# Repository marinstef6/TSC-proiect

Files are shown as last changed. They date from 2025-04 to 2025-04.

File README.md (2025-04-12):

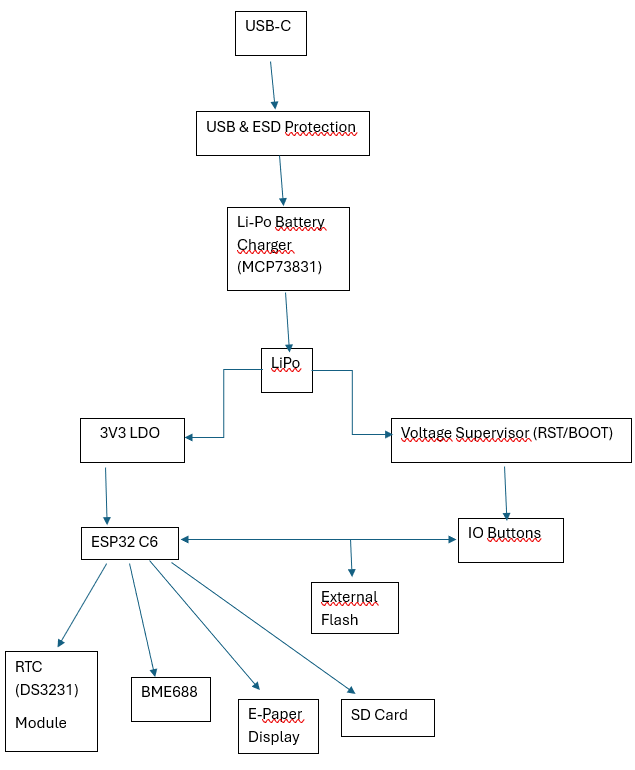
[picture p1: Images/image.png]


**Descriere functionalitate hardware**

Proiectul are la baza microcontroller-ul ESP32-C6, care gestioneaza comunicarea cu toate componentele externe si senzorii conectati. Acest microcontroller ofera conectivitate Wifi si Bluetooth dar si suport pentru interfetele SPI, I2C si UART. Este conectat la 3.3V printr-un regulator de tensiune LDO, acesta primind energie de la o baterie Li-po de 3.7V.
Afisarea informatiile se face utilizand un display E-Paper care este conectat prin inteerfata SPI, oferind un consum redus de energie, acstea fiind mai activ doar cand se fac actualizari pentru ecran. Informatiile pe care le va afisa sunt data, ora, valori senzori etc.
Monitorizarea mediului se face cu ajutorul senzorului BME688, acesta masurand temperatura, umiditatea dar si presiunea atmosferica. Comunica cu microcontroller-ul prin magistrala I2C.
Modulul RTC DS3231 este conectat tot la I2C si mentine ora si data exacta, chiar daca sistemul va fi oprit.
Prin portul USB-C se va face alimentarea sistemuluo care este conectat la circuitul de incarcare de baterie, acesta folosind MCP73831 si astfel controland incarcarea bateriei Li-Po. Tensiunea va fi stabilita la 3.3V pentru alimentarea senzorilor si a microcontroller-ului. 
Circuitul MAX17048 este folosit pentru a monitoriza nivelul incarcarii bateriei si ofera informatii despre tensiune si starea de incarcare prin I2C.
Consumul de energie este dat de ESP32-C6 care va putea sa intre in modul de consum redus si permite functionarea pe termen lung a bateriei. Consumul in regim activ este facut in functie de sarcinile si componentele active in acel moment.
Pentru a stoca, sistemul va folosi o memorie externa de tip NOR Flash conectata cu ajutorul lui SPI dar vom avea si un slot de card SD. Acesta va fi folosit pentru a loga local datele. Butoanele sunt conectate la GPIO-uri si vor fi folosite pentru reset, boot si alte actiuni. 

**Bill Of Materials**

| Componentă | Datasheet | Link produs |
|---|---|---|
| ESP32-C6-WROOM-1-N8 | [Datasheet](https://ro.mouser.com/datasheet/2/891/Espressif_ESP32_C6_WROOM_1__Datasheet_V0_1_PRELIMI-3239987.pdf) | [Link](https://ro.mouser.com/ProductDetail/Espressif-Systems/ESP32-C6-WROOM-1-N8?qs=8Wlm6%252BaMh8ST02Gmwp74cw%3D%3D) |
| MCP73831 | [Datasheet](https://ww1.microchip.com/downloads/aemDocuments/documents/APID/ProductDocuments/DataSheets/MCP73831-Family-Data-Sheet-DS20001984H.pdf) | [Link](https://store.comet.srl.ro/Catalogue/Product/15728/) |
| MAX17048G+T10 | [Datasheet](https://ro.mouser.com/datasheet/2/609/MAX17048_MAX17049-3469099.pdf) | [Link](https://ro.mouser.com/ProductDetail/Analog-Devices-Maxim-Integrated/MAX17048G%2bT10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) |
| USBLC6-2SC6Y | [Datasheet](https://ro.mouser.com/datasheet/2/389/usblc6_2sc6y-1852505.pdf) | [Link](https://ro.mouser.com/ProductDetail/STMicroelectronics/USBLC6-2SC6Y?qs=gNDSiZmRJS%2FOgDexvXkdow%3D%3D) |
| PFMF.050.2 | [Datasheet](https://ro.mouser.com/datasheet/2/358/typ_PFMF-1275918.pdf) | [Link](https://ro.mouser.com/ProductDetail/Schurter/PFMF.050.2?qs=1auRipcfynCums5v1iucSA%3D%3D)|
| SD0805S020S1R0 | [Datasheet](https://ro.mouser.com/datasheet/2/40/schottky-3165252.pdf) | [Link](https://ro.mouser.com/ProductDetail/KYOCERA-AVX/SD0805S020S1R0?qs=jCA%252BPfw4LHbpkAoSnwrdjw%3D%3D) |
| DMG2305UX-7 | [Datasheet](https://www.diodes.com/assets/Datasheets/DMG2305UX.pdf) | [Link](https://ro.mouser.com/ProductDetail/Diodes-Incorporated/DMG2305UX-7?qs=L1DZKBg7t5F%2FNBHrjfxC%252Bg%3D%3D)|
| XC6220A331MR-G (IC4)  | [Datasheet](https://ro.mouser.com/datasheet/2/760/xc6220-3371556.pdf) | [Link](https://ro.mouser.com/ProductDetail/Torex-Semiconductor/XC6220A331MR-G?qs=AsjdqWjXhJ8ZSWznL1J0gg%3D%3D) |
| 112A-TAAR-R03 (J4) | [Datasheet](https://store.comet.bg/download-file.php?id=27596) | [Link](https://store.comet.srl.ro/Catalogue/Product/43497/)|
| MBR0530T3G | [Datasheet](https://www.onsemi.com/products/discrete-power-modules/schottky-diodes-schottky-rectifiers/mbr0530t3g) | [Link](https://ro.mouser.com/ProductDetail/onsemi/MBR0530T3G?qs=3JMERSakebpEmdUS6GetdQ%3D%3D) |  
| MCP73831-2ACI/MC (U5) | [Datasheet](https://ro.mouser.com/datasheet/2/268/MCP73831_Family_Data_Sheet_DS2001984H-3441711.pdf) | [Link](https://ro.mouser.com/ProductDetail/Microchip-Technology/MCP73831-2ACI-MC?qs=hH%252BOa0VZEiBneYTVdpuVdg%3D%3D) |
| FH34SRJ-24S-0.5SH(99) (J1) | [Datasheet](https://ro.mouser.com/datasheet/2/185/FH34SRJ_24S_0_5SH_99__CL0580_1255_6_99_2DDrawing_0-1615044.pdf) | [Link](https://ro.mouser.com/ProductDetail/Hirose-Connector/FH34SRJ-24S-0.5SH99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) |
| DMG2305UX-7 | [Datasheet](https://www.diodes.com/assets/Datasheets/DMG2305UX.pdf) | [Link](https://ro.mouser.com/ProductDetail/Diodes-Incorporated/DMG2305UX-7?qs=L1DZKBg7t5F%2FNBHrjfxC%252Bg%3D%3D) |
| BME688 | [Datasheet](https://ro.mouser.com/datasheet/2/783/bst_bme688_fl000-2307034.pdf) | [Link](https://ro.mouser.com/ProductDetail/Bosch-Sensortec/BME688?qs=IS%252B4QmGtzzqQoVDscqwx3A%3D%3D) |
| BD5229G-TR (IC1) | [Datasheet](https://fscdn.rohm.com/en/products/databook/datasheet/ic/power/voltage_detector/bd52xxg-e.pdf) | [Link](https://ro.mouser.com/ProductDetail/ROHM-Semiconductor/BD5229G-TR?qs=4kLU8WoGk0vvnhrrYwdszw%3D%3D) |
| DS3231SN# (U3) | [Datasheet](https://ro.mouser.com/datasheet/2/609/DS3231-3421123.pdf) | [Link](https://ro.mouser.com/ProductDetail/Analog-Devices-Maxim-Integrated/DS3231SN?qs=1eQvB6Dk1vhUlr8%2FOrV0Fw%3D%3D) |
| CPH3225A | [Datasheet](https://ro.mouser.com/datasheet/2/360/Seiko_Instruments_MicroBattery_E_20230330_2024Jan_-3561061.pdf) | [Link](https://ro.mouser.com/ProductDetail/Seiko-Semiconductors/CPH3225A?qs=3etwrb1wR%252BhUOph6lAO7eg%3D%3D) |
| PGB1010603MR | [Datasheet](https://www.littelfuse.com/assetdocs/pulseguard-esd-suppressors-pgb1-datasheet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) | [Link](https://ro.mouser.com/ProductDetail/Littelfuse/PGB1010603MR?qs=gu7KAQ731URLg4GSnNNN7Q%3D%3D) |
| W25Q512JVEIQ (U1) | [Datasheet](https://ro.mouser.com/datasheet/2/949/Winbond_W25Q512JV_Datasheet-3240039.pdf) | [Link](https://ro.mouser.com/ProductDetail/Winbond/W25Q512JVEIQ?qs=l7cgNqFNU1jw6svr3at6tA%3D%3D) |
| Qwiic connector 4-pin Accessories (J3) | [Datasheet]() | [Link](https://ro.mouser.com/ProductDetail/Adafruit/4208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) |
| C1 | [Datasheet](https://ro.mouser.com/datasheet/2/447/UPY_GPHC_X7R_6_3V_to_250V_24-3441574.pdf) | [Link](https://ro.mouser.com/ProductDetail/YAGEO/CC0402KRX7R7BB104?qs=AgBp2OyFlx%252BSOyhfyS7hpw%3D%3D) |
| C2 | [Datasheet](https://ro.mouser.com/datasheet/2/447/UPY_GPHC_X7R_6_3V_to_250V_24-3441574.pdf) | [Link](https://ro.mouser.com/ProductDetail/YAGEO/CC0402KRX7R7BB104?qs=AgBp2OyFlx%252BSOyhfyS7hpw%3D%3D) |
| C1_BAT | [Datasheet](https://ro.mouser.com/datasheet/2/447/upy_gphc_x5r_4v_to_50v-3461255.pdf) | [Link](https://ro.mouser.com/ProductDetail/YAGEO/CC0402MPX5R5BB475?qs=mzRxyRlhVdsRoWExm6hPvg%3D%3D) |
| C1_BAT1 | [Datasheet](https://ro.mouser.com/datasheet/2/447/upy_gphc_x5r_4v_to_50v-3461255.pdf) | [Link](https://ro.mouser.com/ProductDetail/YAGEO/CC0402MPX5R5BB475?qs=mzRxyRlhVdsRoWExm6hPvg%3D%3D) | 
| C1_BAT2 | [Datasheet](https://ro.mouser.com/datasheet/2/447/upy_gphc_x5r_4v_to_50v-3461255.pdf) | [Link](https://ro.mouser.com/ProductDetail/YAGEO/CC0402MPX5R5BB475?qs=mzRxyRlhVdsRoWExm6hPvg%3D%3D) |  
| C2_BAT | [Datasheet](https://ro.mouser.com/datasheet/2/447/upy_gphc_x5r_4v_to_50v-3461255.pdf) | [Link](https://ro.mouser.com/ProductDetail/YAGEO/CC0402MPX5R5BB475?qs=mzRxyRlhVdsRoWExm6hPvg%3D%3D) |
| C4 | [Datasheet](https://ro.mouser.com/datasheet/2/447/upy_gphc_x5r_4v_to_50v-3461255.pdf) | [Link](https://ro.mouser.com/ProductDetail/YAGEO/CC0402KPX5R8BB105?qs=mzRxyRlhVduNCG5kLC2PGw%3D%3D) |
| C3 | [Datasheet]() | [Link]() |
| C4_USB | [Datasheet](https://ro.mouser.com/datasheet/2/447/UPY_GPHC_X7R_6_3V_to_250V_24-3441574.pdf) | [Link](https://ro.mouser.com/ProductDetail/YAGEO/CC0402KRX7R7BB104?qs=AgBp2OyFlx%252BSOyhfyS7hpw%3D%3D) |
| C5 | [Datasheet](https://ro.mouser.com/datasheet/2/447/UPY_GPHC_X6S_4V_to_50V_5-3461239.pdf) | [Link](https://ro.mouser.com/ProductDetail/YAGEO/CC0402KRX6S8BB105?qs=W0yvOO0ixfHpmgj3WKoR4Q%3D%3D) |
| C5_USB | [Datasheet](https://ro.mouser.com/datasheet/2/447/upy_gphc_x5r_4v_to_50v-3461255.pdf) | [Link](https://ro.mouser.com/ProductDetail/YAGEO/CC0402MPX5R5BB475?qs=mzRxyRlhVdsRoWExm6hPvg%3D%3D) |
| C6 | [Datasheet](https://ro.mouser.com/datasheet/2/447/UPY_GPHC_X7R_6_3V_to_250V_24-3441574.pdf) | [Link](https://ro.mouser.com/ProductDetail/YAGEO/CC0402KRX7R7BB104?qs=AgBp2OyFlx%252BSOyhfyS7hpw%3D%3D) |
| C7 | [Datasheet](https://ro.mouser.com/datasheet/2/447/upy_gphc_x5r_4v_to_50v-3461255.pdf) | [Link](https://ro.mouser.com/ProductDetail/YAGEO/CC0402MRX5R4BB106?qs=tS%2FAHvPQ%2F561gTjBOiVihQ%3D%3D) |
| C8 | [Datasheet](https://ro.mouser.com/datasheet/2/447/UPY_GPHC_X7R_6_3V_to_250V_24-3441574.pdf) | [Link](https://ro.mouser.com/ProductDetail/YAGEO/CC0402KRX7R7BB104?qs=AgBp2OyFlx%252BSOyhfyS7hpw%3D%3D) |
| C9 | [Datasheet](https://ro.mouser.com/datasheet/2/447/UPY_GPHC_X7R_6_3V_to_250V_24-3441574.pdf) | [Link](https://ro.mouser.com/ProductDetail/YAGEO/CC0402KRX7R7BB104?qs=AgBp2OyFlx%252BSOyhfyS7hpw%3D%3D) |
| C10 | [Datasheet](https://ro.mouser.com/datasheet/2/447/UPY_GPHC_X7R_6_3V_to_250V_24-3441574.pdf) | [Link](https://ro.mouser.com/ProductDetail/YAGEO/CC0402KRX7R7BB104?qs=AgBp2OyFlx%252BSOyhfyS7hpw%3D%3D) |
| C10_SUPERCAP | [Datasheet](https://ro.mouser.com/datasheet/2/360/Seiko_Instruments_MicroBattery_E_20230330_2024Jan_-3561061.pdf) | [Link](https://ro.mouser.com/ProductDetail/Seiko-Semiconductors/CPH3225A?qs=3etwrb1wR%252BhUOph6lAO7eg%3D%3D) |
| CHANGE_BUTTON | [Datasheet](https://ro.mouser.com/datasheet/2/1490/SOF_data_sheet-3304259.pdf) | [Link](https://ro.mouser.com/ProductDetail/Mitsumi/SOF-232HNT?qs=Imq1NPwxi77Mt0U54xXTVA%3D%3D) |
| RESET_BUTTON | [Datasheet](https://ro.mouser.com/datasheet/2/1490/SOF_data_sheet-3304259.pdf) | [Link](https://ro.mouser.com/ProductDetail/Mitsumi/SOF-232HNT?qs=Imq1NPwxi77Mt0U54xXTVA%3D%3D) |
| BOOT_BUTTON | [Datasheet](https://ro.mouser.com/datasheet/2/1490/SOF_data_sheet-3304259.pdf) | [Link](https://ro.mouser.com/ProductDetail/Mitsumi/SOF-232HNT?qs=Imq1NPwxi77Mt0U54xXTVA%3D%3D) |  
| CHG_LED | [Datasheet]() | [Link]() |
| C_DELAY | [Datasheet](https://ro.mouser.com/datasheet/2/447/UPY_GPHC_X7R_6_3V_to_250V_24-3441574.pdf) | [Link](https://ro.mouser.com/ProductDetail/YAGEO/CC0402KRX7R7BB104?qs=AgBp2OyFlx%252BSOyhfyS7hpw%3D%3D) |
| D2 | [Datasheet](https://ro.mouser.com/datasheet/2/40/schottky-3165252.pdf) | [Link](https://ro.mouser.com/ProductDetail/KYOCERA-AVX/SD0805S020S1R0?qs=jCA%252BPfw4LHbpkAoSnwrdjw%3D%3D) |
| D3 | [Datasheet](https://www.onsemi.com/products/discrete-power-modules/schottky-diodes-schottky-rectifiers/mbr0530t3g) | [Link](https://ro.mouser.com/ProductDetail/onsemi/MBR0530T3G?qs=3JMERSakebpEmdUS6GetdQ%3D%3D) |
| D4 | [Datasheet](https://www.onsemi.com/products/discrete-power-modules/schottky-diodes-schottky-rectifiers/mbr0530t3g) | [Link](https://ro.mouser.com/ProductDetail/onsemi/MBR0530T3G?qs=3JMERSakebpEmdUS6GetdQ%3D%3D) |
| D5 | [Datasheet](https://www.onsemi.com/products/discrete-power-modules/schottky-diodes-schottky-rectifiers/mbr0530t3g) | [Link](https://ro.mouser.com/ProductDetail/onsemi/MBR0530T3G?qs=3JMERSakebpEmdUS6GetdQ%3D%3D) |
| D6 | [Datasheet](https://www.littelfuse.com/assetdocs/pulseguard-esd-suppressors-pgb1-datasheet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) | [Link](https://ro.mouser.com/ProductDetail/Littelfuse/PGB1010603MR?qs=gu7KAQ731URLg4GSnNNN7Q%3D%3D) |
| D7 | [Datasheet](https://ro.mouser.com/datasheet/2/40/schottky-3165252.pdf) | [Link](https://ro.mouser.com/ProductDetail/KYOCERA-AVX/SD0805S020S1R0?qs=jCA%252BPfw4LHbpkAoSnwrdjw%3D%3D) |
| D8 | [Datasheet](https://www.littelfuse.com/assetdocs/pulseguard-esd-suppressors-pgb1-datasheet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) | [Link](https://ro.mouser.com/ProductDetail/Littelfuse/PGB1010603MR?qs=gu7KAQ731URLg4GSnNNN7Q%3D%3D) |
| D9 | [Datasheet](https://www.littelfuse.com/assetdocs/pulseguard-esd-suppressors-pgb1-datasheet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) | [Link](https://ro.mouser.com/ProductDetail/Littelfuse/PGB1010603MR?qs=gu7KAQ731URLg4GSnNNN7Q%3D%3D) |
| D10 | [Datasheet](https://www.littelfuse.com/assetdocs/pulseguard-esd-suppressors-pgb1-datasheet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) | [Link](https://ro.mouser.com/ProductDetail/Littelfuse/PGB1010603MR?qs=gu7KAQ731URLg4GSnNNN7Q%3D%3D) |
| D11 | [Datasheet](https://www.littelfuse.com/assetdocs/pulseguard-esd-suppressors-pgb1-datasheet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) | [Link](https://ro.mouser.com/ProductDetail/Littelfuse/PGB1010603MR?qs=gu7KAQ731URLg4GSnNNN7Q%3D%3D) |
| D12 | [Datasheet](https://www.littelfuse.com/assetdocs/pulseguard-esd-suppressors-pgb1-datasheet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) | [Link](https://ro.mouser.com/ProductDetail/Littelfuse/PGB1010603MR?qs=gu7KAQ731URLg4GSnNNN7Q%3D%3D) |
| EPD_C1 | [Datasheet](https://ro.mouser.com/datasheet/2/396/TAIY_S_A0012396493_1-2514439.pdf) | [Link](https://ro.mouser.com/ProductDetail/TAIYO-YUDEN/UMK105CBJ105MV-F?qs=lkMpTOwszhfe5N0wQnb5vQ%3D%3D) |
| EPD_C2 | [Datasheet](https://ro.mouser.com/datasheet/2/396/TAIY_S_A0012396493_1-2514439.pdf) | [Link](https://ro.mouser.com/ProductDetail/TAIYO-YUDEN/UMK105CBJ105MV-F?qs=lkMpTOwszhfe5N0wQnb5vQ%3D%3D) |  
| EPD_C5 | [Datasheet](https://ro.mouser.com/datasheet/2/396/TAIY_S_A0012396493_1-2514439.pdf) | [Link](https://ro.mouser.com/ProductDetail/TAIYO-YUDEN/UMK105CBJ105MV-F?qs=lkMpTOwszhfe5N0wQnb5vQ%3D%3D) |
| EPD_C6 | [Datasheet](https://ro.mouser.com/datasheet/2/396/TAIY_S_A0012396493_1-2514439.pdf) | [Link](https://ro.mouser.com/ProductDetail/TAIYO-YUDEN/UMK105CBJ105MV-F?qs=lkMpTOwszhfe5N0wQnb5vQ%3D%3D) |
| EPD_C7 | [Datasheet](https://ro.mouser.com/datasheet/2/396/TAIY_S_A0012396493_1-2514439.pdf) | [Link](https://ro.mouser.com/ProductDetail/TAIYO-YUDEN/UMK105CBJ105MV-F?qs=lkMpTOwszhfe5N0wQnb5vQ%3D%3D) |
| EPD_C8 | [Datasheet](https://ro.mouser.com/datasheet/2/396/TAIY_S_A0012396493_1-2514439.pdf) | [Link](https://ro.mouser.com/ProductDetail/TAIYO-YUDEN/UMK105CBJ105MV-F?qs=lkMpTOwszhfe5N0wQnb5vQ%3D%3D) |
| EPD_C9 | [Datasheet](https://ro.mouser.com/datasheet/2/396/TAIY_S_A0012396493_1-2514439.pdf) | [Link](https://ro.mouser.com/ProductDetail/TAIYO-YUDEN/UMK105CBJ105MV-F?qs=lkMpTOwszhfe5N0wQnb5vQ%3D%3D) |
| EPD_C10 | [Datasheet](https://ro.mouser.com/datasheet/2/396/TAIY_S_A0012396493_1-2514439.pdf) | [Link](https://ro.mouser.com/ProductDetail/TAIYO-YUDEN/UMK105CBJ105MV-F?qs=lkMpTOwszhfe5N0wQnb5vQ%3D%3D) |
| EPD_C11 | [Datasheet](https://ro.mouser.com/datasheet/2/396/TAIY_S_A0012396493_1-2514439.pdf) | [Link](https://ro.mouser.com/ProductDetail/TAIYO-YUDEN/UMK105CBJ105MV-F?qs=lkMpTOwszhfe5N0wQnb5vQ%3D%3D) |
| EPD_C12 | [Datasheet](https://ro.mouser.com/datasheet/2/396/TAIY_S_A0012396493_1-2514439.pdf) | [Link](https://ro.mouser.com/ProductDetail/TAIYO-YUDEN/UMK105CBJ105MV-F?qs=lkMpTOwszhfe5N0wQnb5vQ%3D%3D) |
| J2 | [Datasheet](https://ro.mouser.com/datasheet/2/837/GCT_USB4110_Product_Drawing___20k_cycles-3455479.pdf) | [Link](https://ro.mouser.com/ProductDetail/GCT/USB4110-GF-A?qs=KUoIvG%2F9IlYiZvIXQjyJeA%3D%3D) |
| L1 | [Datasheet](https://www.we-online.com/components/products/datasheet/744043680.pdf) | [Link](https://ro.mouser.com/ProductDetail/Wurth-Elektronik/744043680?qs=PGXP4M47uW6VkZq%252BkzjrHA%3D%3D) |
| Q1 | [Datasheet](https://www.vishay.com/docs/62424/sq2362ces.pdf) | [Link](https://ro.mouser.com/ProductDetail/Vishay-Siliconix/SQ2362CES-T1_GE3?qs=i8QVZAFTkqR3b4Fby5FULg%3D%3D) |
| Q2 | [Datasheet](https://www.vishay.com/docs/62424/sq2362ces.pdf) | [Link](https://ro.mouser.com/ProductDetail/Vishay-Siliconix/SQ2362CES-T1_GE3?qs=i8QVZAFTkqR3b4Fby5FULg%3D%3D) |
| Q3 | [Datasheet](https://www.vishay.com/docs/63399/si1308edl.pdf) | [Link](https://ro.mouser.com/ProductDetail/Vishay-Semiconductors/SI1308EDL-T1-GE3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) |
| R1 | [Datasheet](https://www.vishay.com/docs/28726/uxa0204.pdf) | [Link](https://ro.mouser.com/ProductDetail/Vishay-Beyschlag/UXB02070G1002BCU00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) |
| R1-PINH | [Datasheet](https://www.vishay.com/docs/28726/uxa0204.pdf) | [Link](https://ro.mouser.com/ProductDetail/Vishay-Beyschlag/UXB02070G1002BCU00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) |  
| R1-PINH1 | [Datasheet](https://www.vishay.com/docs/28726/uxa0204.pdf) | [Link](https://ro.mouser.com/ProductDetail/Vishay-Beyschlag/UXB02070G1002BCU00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) |
| R1_BAT | [Datasheet](https://www.vishay.com/docs/20024/dcrcwife3.pdf) | [Link](https://ro.mouser.com/ProductDetail/Vishay-Dale/CRCW121020R0JNEAIF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) |
| R1_PWRUSB | [Datasheet](https://www.vishay.com/docs/20024/dcrcwife3.pdf) | [Link](https://ro.mouser.com/ProductDetail/Vishay-Dale/CRCW1210100KJNEAIF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) |
| R2 | [Datasheet](https://ro.mouser.com/datasheet/2/210/kamaya_watc_s_a0000242430_1-1991191.pdf) | [Link](https://ro.mouser.com/ProductDetail/Walsin/WR04W2R20FTR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) |
| R2-USB | [Datasheet]() | [Link]() |
| R2-USB1 | [Datasheet]() | [Link]() |
| R2_BAT | [Datasheet](https://www.vishay.com/docs/20024/dcrcwife3.pdf) | [Link](https://ro.mouser.com/ProductDetail/Vishay-Dale/CRCW20102K00JNEFIF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) |
| R2-PINH | [Datasheet](https://www.vishay.com/docs/28726/uxa0204.pdf) | [Link](https://ro.mouser.com/ProductDetail/Vishay-Beyschlag/UXB02070G1002BCU00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) |
| R2-PINH1 | [Datasheet](https://www.vishay.com/docs/28726/uxa0204.pdf) | [Link](https://ro.mouser.com/ProductDetail/Vishay-Beyschlag/UXB02070G1002BCU00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) |
| R3 | [Datasheet](https://www.vishay.com/docs/28726/uxa0204.pdf) | [Link](https://ro.mouser.com/ProductDetail/Vishay-Beyschlag/UXB02070G1002BCU00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) |
| R4 | [Datasheet](https://www.vishay.com/docs/28726/uxa0204.pdf) | [Link](https://ro.mouser.com/ProductDetail/Vishay-Beyschlag/UXB02070G1002BCU00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) |
| R5 | [Datasheet](https://www.vishay.com/docs/28726/uxa0204.pdf) | [Link](https://ro.mouser.com/ProductDetail/Vishay-Beyschlag/UXB02070G1002BCU00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) |
| R6 | [Datasheet](https://www.vishay.com/docs/28726/uxa0204.pdf) | [Link](https://ro.mouser.com/ProductDetail/Vishay-Beyschlag/UXB02070G1002BCU00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) |
| R7 | [Datasheet](https://www.vishay.com/docs/28726/uxa0204.pdf) | [Link](https://ro.mouser.com/ProductDetail/Vishay-Beyschlag/UXB02070G1002BCU00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) |
| R8 | [Datasheet](https://www.vishay.com/docs/28726/uxa0204.pdf) | [Link](https://ro.mouser.com/ProductDetail/Vishay-Beyschlag/UXB02070G1002BCU00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) |
| R9 | [Datasheet](https://www.vishay.com/docs/28726/uxa0204.pdf) | [Link](https://ro.mouser.com/ProductDetail/Vishay-Beyschlag/UXB02070G1002BCU00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) |
| R10 | [Datasheet](https://www.vishay.com/docs/28726/uxa0204.pdf) | [Link](https://ro.mouser.com/ProductDetail/Vishay-Beyschlag/UXB02070G1002BCU00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) |
| R_BOOT | [Datasheet](https://www.vishay.com/docs/28726/uxa0204.pdff) | [Link](https://ro.mouser.com/ProductDetail/Vishay-Beyschlag/UXB02070G1002BCU00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) |
| R_CAPACITOR | [Datasheet](https://ro.mouser.com/datasheet/2/210/kamaya_products_RGC__english_20170424_101024-1651573.pdf) | [Link](https://ro.mouser.com/ProductDetail/Kamaya/RGC1-16K15R0BTP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) |  
| R_CHANGE | [Datasheet](https://www.vishay.com/docs/28726/uxa0204.pdf) | [Link](https://ro.mouser.com/ProductDetail/Vishay-Beyschlag/UXB02070G1002BCU00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) |
| R_CL1 | [Datasheet](https://www.vishay.com/docs/28726/uxa0204.pdf) | [Link](https://ro.mouser.com/ProductDetail/Vishay-Beyschlag/UXB02070G1002BCU00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) |
| R_RESET | [Datasheet](https://www.vishay.com/docs/28726/uxa0204.pdf) | [Link](https://ro.mouser.com/ProductDetail/Vishay-Beyschlag/UXB02070G1002BCU00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) |
| SENSOR2 | [Datasheet](https://ro.mouser.com/datasheet/2/783/BST_BME680_DS001-1509608.pdf) | [Link](https://ro.mouser.com/ProductDetail/Bosch-Sensortec/BME680?qs=v271MhAjFHjo0yA%2FC4OnDQ%3D%3D) |
| SJ1 | [Datasheet](https://ro.mouser.com/datasheet/2/972/cjs-1827353.pdf) | [Link](https://ro.mouser.com/ProductDetail/Nidec-Components/CJS-1201B?qs=XeJtXLiO41SSSa2Z7HG9Iw%3D%3) |
| TP1 | [Datasheet](https://ro.mouser.com/datasheet/2/418/4/NG_DS_1773266_A-732548.pdf) | [Link](https://ro.mouser.com/ProductDetail/TE-Connectivity-Holsworthy/RCW-0C?qs=ip69W3eHERVcN99nMRbYaQ%3D%3D) |
| TP2 | [Datasheet](https://ro.mouser.com/datasheet/2/418/4/NG_DS_1773266_A-732548.pdf) | [Link](https://ro.mouser.com/ProductDetail/TE-Connectivity-Holsworthy/RCW-0C?qs=ip69W3eHERVcN99nMRbYaQ%3D%3D) |
| TP3 | [Datasheet](https://ro.mouser.com/datasheet/2/418/4/NG_DS_1773266_A-732548.pdf) | [Link](https://ro.mouser.com/ProductDetail/TE-Connectivity-Holsworthy/RCW-0C?qs=ip69W3eHERVcN99nMRbYaQ%3D%3D) |
| TP4 | [Datasheet](https://ro.mouser.com/datasheet/2/418/4/NG_DS_1773266_A-732548.pdf) | [Link](https://ro.mouser.com/ProductDetail/TE-Connectivity-Holsworthy/RCW-0C?qs=ip69W3eHERVcN99nMRbYaQ%3D%3D) |
| TP5 | [Datasheet](https://ro.mouser.com/datasheet/2/418/4/NG_DS_1773266_A-732548.pdf) | [Link](https://ro.mouser.com/ProductDetail/TE-Connectivity-Holsworthy/RCW-0C?qs=ip69W3eHERVcN99nMRbYaQ%3D%3D) |
| TP6 | [Datasheet](https://ro.mouser.com/datasheet/2/418/4/NG_DS_1773266_A-732548.pdf) | [Link](https://ro.mouser.com/ProductDetail/TE-Connectivity-Holsworthy/RCW-0C?qs=ip69W3eHERVcN99nMRbYaQ%3D%3D) |
| TP7 | [Datasheet](https://ro.mouser.com/datasheet/2/418/4/NG_DS_1773266_A-732548.pdf) | [Link](https://ro.mouser.com/ProductDetail/TE-Connectivity-Holsworthy/RCW-0C?qs=ip69W3eHERVcN99nMRbYaQ%3D%3D) |
| TP8 | [Datasheet](https://ro.mouser.com/datasheet/2/418/4/NG_DS_1773266_A-732548.pdf) | [Link](https://ro.mouser.com/ProductDetail/TE-Connectivity-Holsworthy/RCW-0C?qs=ip69W3eHERVcN99nMRbYaQ%3D%3D) |
| TP9 | [Datasheet](https://ro.mouser.com/datasheet/2/418/4/NG_DS_1773266_A-732548.pdf) | [Link](https://ro.mouser.com/ProductDetail/TE-Connectivity-Holsworthy/RCW-0C?qs=ip69W3eHERVcN99nMRbYaQ%3D%3D) |
| TP10 | [Datasheet](https://ro.mouser.com/datasheet/2/418/4/NG_DS_1773266_A-732548.pdf) | [Link](https://ro.mouser.com/ProductDetail/TE-Connectivity-Holsworthy/RCW-0C?qs=ip69W3eHERVcN99nMRbYaQ%3D%3D) |  
| TP11 | [Datasheet](https://ro.mouser.com/datasheet/2/418/4/NG_DS_1773266_A-732548.pdf) | [Link](https://ro.mouser.com/ProductDetail/TE-Connectivity-Holsworthy/RCW-0C?qs=ip69W3eHERVcN99nMRbYaQ%3D%3D) |
| TP12 | [Datasheet](https://ro.mouser.com/datasheet/2/418/4/NG_DS_1773266_A-732548.pdf) | [Link](https://ro.mouser.com/ProductDetail/TE-Connectivity-Holsworthy/RCW-0C?qs=ip69W3eHERVcN99nMRbYaQ%3D%3D) |
| TP13 | [Datasheet](https://ro.mouser.com/datasheet/2/418/4/NG_DS_1773266_A-732548.pdf) | [Link](https://ro.mouser.com/ProductDetail/TE-Connectivity-Holsworthy/RCW-0C?qs=ip69W3eHERVcN99nMRbYaQ%3D%3D) |
| TP14 | [Datasheet](https://ro.mouser.com/datasheet/2/418/4/NG_DS_1773266_A-732548.pdf) | [Link](https://ro.mouser.com/ProductDetail/TE-Connectivity-Holsworthy/RCW-0C?qs=ip69W3eHERVcN99nMRbYaQ%3D%3D) |
| TP15 | [Datasheet](https://ro.mouser.com/datasheet/2/418/4/NG_DS_1773266_A-732548.pdf) | [Link](https://ro.mouser.com/ProductDetail/TE-Connectivity-Holsworthy/RCW-0C?qs=ip69W3eHERVcN99nMRbYaQ%3D%3D) |
| TP16 | [Datasheet](https://ro.mouser.com/datasheet/2/418/4/NG_DS_1773266_A-732548.pdf) | [Link](https://ro.mouser.com/ProductDetail/TE-Connectivity-Holsworthy/RCW-0C?qs=ip69W3eHERVcN99nMRbYaQ%3D%3D) |
| TP17 | [Datasheet](https://ro.mouser.com/datasheet/2/418/4/NG_DS_1773266_A-732548.pdf) | [Link](https://ro.mouser.com/ProductDetail/TE-Connectivity-Holsworthy/RCW-0C?qs=ip69W3eHERVcN99nMRbYaQ%3D%3D) |
| U2 | [Datasheet](https://ro.mouser.com/datasheet/2/891/Espressif_ESP32_C6_WROOM_1__Datasheet_V0_1_PRELIMI-3239987.pdf) | [Link](https://ro.mouser.com/ProductDetail/Espressif-Systems/ESP32-C6-WROOM-1-N8?qs=8Wlm6%252BaMh8ST02Gmwp74cw%3D%3D) |

**Descriere pini ESP32-C6**

Pinii microcontroller-ului ESP32-C6 sunt folositi in cadrul a cinci categorii:

1. Interfata SPI, care este folosita pentru  comunicarea componentelor care necesita viteza mare de transfer. Pinii utilizati sunt:
- IO0 - linia MOSI unde microcontrollerul va trimite date catre perifericele SPI
- IO1 - linia MISO unde ESP32-C6 va primi date de la cardul SD.
- IO2 - linia SCK care va genera semnalul de ceas pentru a face sincronizarea SPI
- IO3 - linia CS pentru memoria Flash NOR
- IO4 - linia CS pentru display-ul E-paper
- IO5 - linia CS pentru slotul de card SD
- IO6, IO7, IO8 - pentru semnalele de control ale E-Paper-ului: reset, busy, data/command(DC)
Se vor folosi acesti pini pentru a nu intra in conflicte cu alte interfete si vor permite o rutare eficienta a traseelor pe placa.

2. Interfata I2C, va fi folosita pentru a conecta senzorii de mediu si a circuitelor de monitorizare a tensiunii sau a timpului. Aceasta interfata va conecta si componentele: BME668, MAX17048, DS3231 Pinii folositi sunt:
- IO15 - linia SCL, folosita pentru semnalul de ceas
- IO16 - linia SDA, care va transmite date bidirectional intre microcontroller si perifericele I2C
Acesti pini sunt folositi pentru a nu se suprapune cu cei de la SPI sau UART si pentru a permite extinderea prin Qwiic.

3. Interfata UART, care este folosita pentru debbuging, comunicare seriala sau conectare la modul extern. Pinii utilizati sunt:
- IO17 - TXD, care este linia de iesire a datelor de la ESP32 catre PC sau consola
- IO18 - RXD, care este linia de intrare a datelor catre ESP32
Acesti pini sunt utili in faza de dezvoltare pentru testare dar pot fi folositi daca UART nu este necesar in aplicatia finala.

4. Pini GPIO care sunt folositi pentru butoanele boot, reset sau change. Pinii folositi sunt:
- IO9 - este folosit pentru BOOT si permite intrarea in modul de programare
- EN - este pinul hardware RESET al ESP32-C6
- IO10, IO11 - sunt utilizati pentru butoane suplimentare care au diverse actiuni in aplicatie.
Acesti pini au fost folositi pentru ca sunt disponibili in schema de referinta ESP32-C6 si nu sunt partajati cu perifericele.

5. Alimentare, unde se vor folosi:
- 3V3 - este intrarea de alimentare stabilizata la 3.3V si provine din regulatorul LDO  alimentat de la bateria Li-Po
- GND care este conexiunea de masa

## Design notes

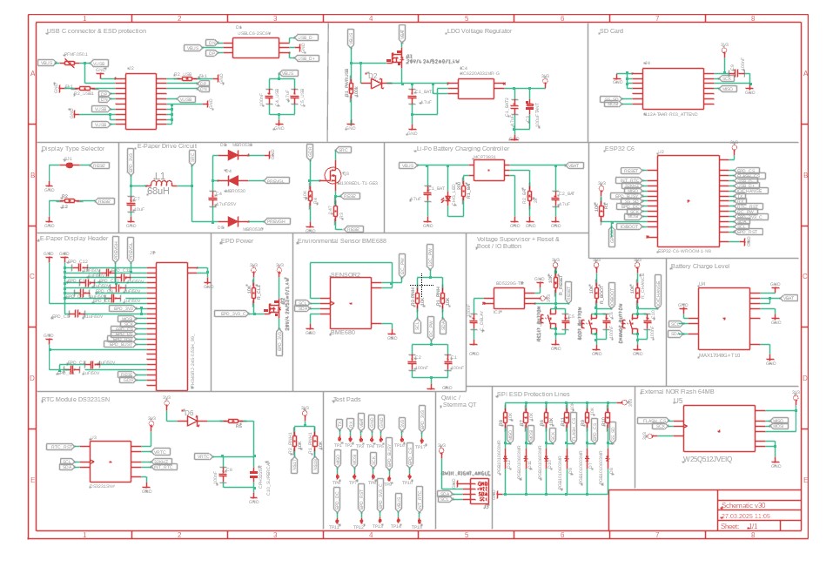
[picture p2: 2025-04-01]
Images/schematic.jpg

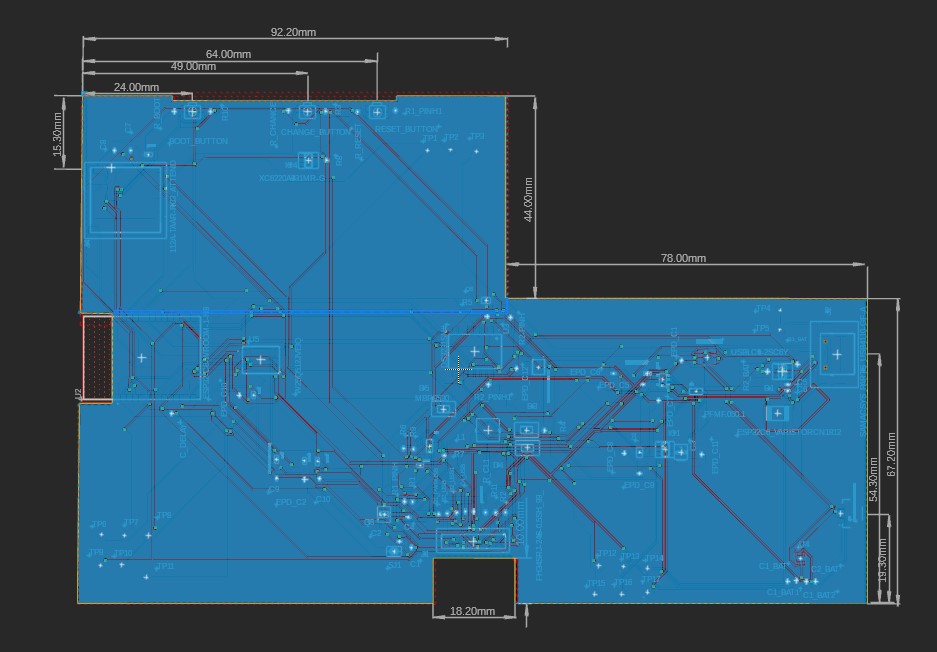
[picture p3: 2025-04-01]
Images/plan_masa_bottom.jpg

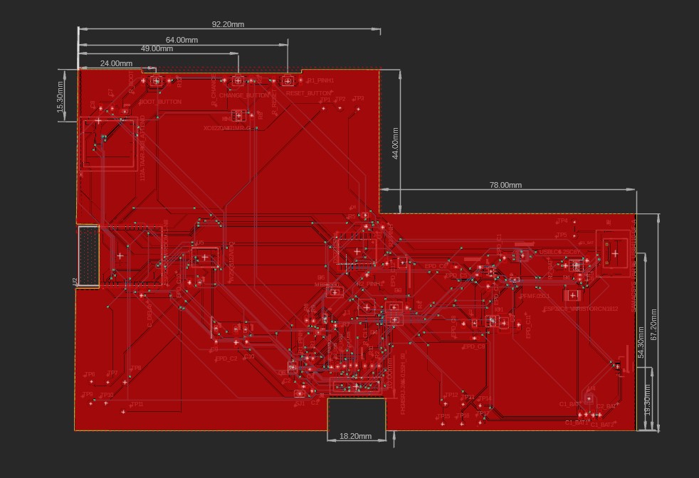
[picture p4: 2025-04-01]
Images/plan_masa_top.jpg

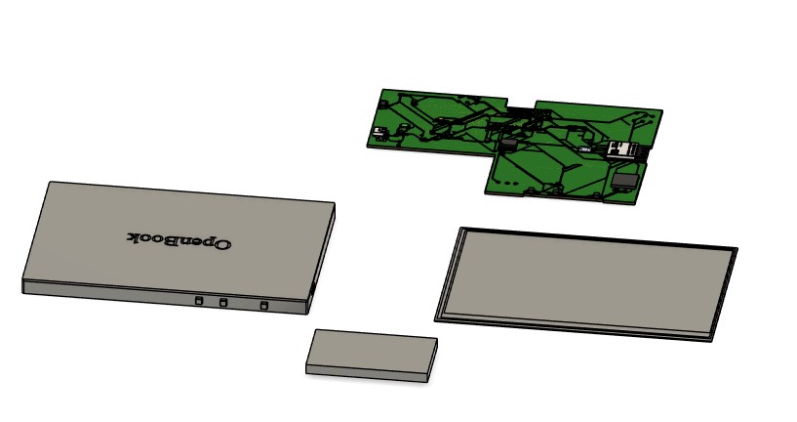
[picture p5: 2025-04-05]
Images/poza_finala.jpg

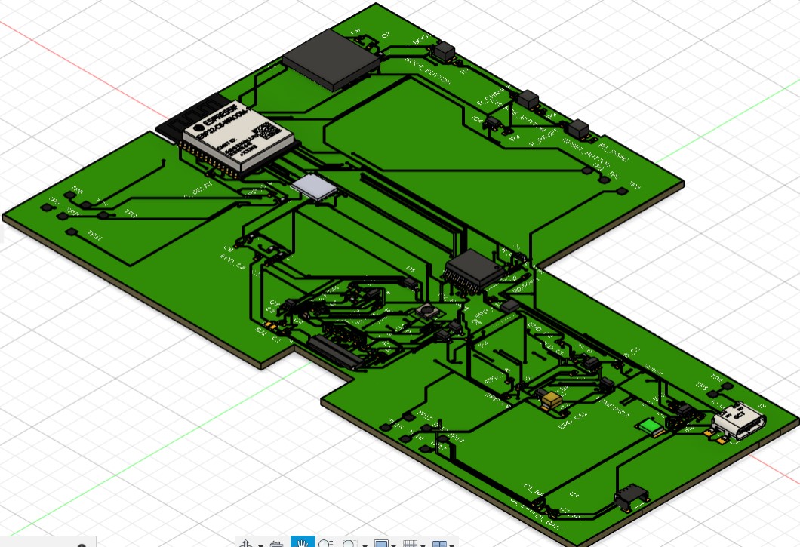
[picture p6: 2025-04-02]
Images/placa_3d.jpg

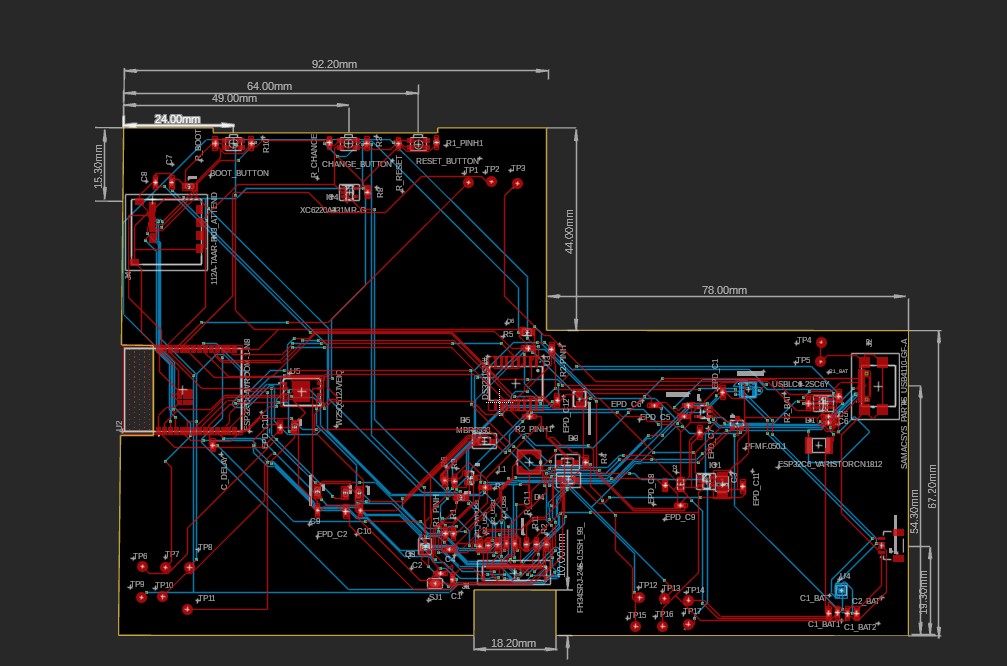
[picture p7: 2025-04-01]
Images/pcb.jpg

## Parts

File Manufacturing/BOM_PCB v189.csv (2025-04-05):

Qty | Value | Device | Package | Parts | Description | ARROW_PART_NUMBER | ARROW_PRICE-STOCK | AVAILABILITY | CENTROID_NOT_SPECIFIED | CHECK_PRICES | COPYRIGHT | DATASHEET | DESCRIPTION | DIGIKEY_DESCRIPTION | DIGIKEY_PART_NUMBER | HEIGHT | LEAD_FREE | MANUFACTURER_NAME | MANUFACTURER_PART_NUMBER | MF | MFR_NAME | MOUSER_PART_NUMBER | MOUSER_PRICE-STOCK | MOUSER_TESTING_PART_NUMBER | MOUSER_TESTING_PRICE-STOCK | MP | MPN | PACKAGE | POPULARITY | PREFIX | PRICE | PROD_ID | PURCHASE-URL | ROHS | SNAPEDA_LINK | SPICEMODEL | SPICEPREFIX | TANT | TEMPERATURE_RANGE_HIGH | TEMPERATURE_RANGE_LOW | TP_SIGNAL_NAME | VALUE
1 |  | ADAFRUIT_LEDCHIP-LED0603 | ADAFRUIT_CHIP-LED0603 | CHG_LED | LED
1 |  | ESP32_WROVER_EAGLE-LTSPICE_CC0402 | ESP32_WROVER_EAGLE-LTSPICE_C0402 | C5 | CAPACITOR, European symbol |  |  |  |  |  |  |  |  |  |  |  |  |  |  |  |  |  |  |  |  |  |  |  |  |  |  |  |  |  |  | NONE | C
1 |  | SJ | SJ | SJ1 | SMD solder JUMPER |  |  |  |  |  |  |  |  |  |  |  |  |  |  |  |  |  |  |  |  |  |  |  | 3
1 | 0.1uF/50V | ESP32_WROVER_EAGLE-LTSPICE_CC0402 | ESP32_WROVER_EAGLE-LTSPICE_C0402 | EPD_C5 | CAPACITOR, European symbol |  |  |  |  |  |  |  |  |  |  |  |  |  |  |  |  |  |  |  |  |  |  |  |  |  |  |  |  |  |  | NONE | C
1 | 0.47 | ESP32_WROVER_EAGLE-LTSPICE_RR0402 | ESP32_WROVER_EAGLE-LTSPICE_R0402 | R3 | RESISTOR, European symbol |  |  |  |  |  |  |  |  |  |  |  |  |  |  |  |  |  |  |  |  |  |  |  |  |  |  |  |  |  |  | NONE | R
1 | 100k | ESP32_WROVER_EAGLE-LTSPICE_RR0402 | ESP32_WROVER_EAGLE-LTSPICE_R0402 | R1_PWRUSB | RESISTOR, European symbol |  |  |  |  |  |  |  |  |  |  |  |  |  |  |  |  |  |  |  |  |  |  |  |  |  |  |  |  |  |  | NONE | R
5 | 100nF | EAGLE-LTSPICE_CC0402 | EAGLE-LTSPICE_C0402 | C4_USB, C6, C8, C9, C10 | CAPACITOR, European symbol |  |  |  |  |  |  |  |  |  |  |  |  |  |  |  |  |  |  |  |  |  |  |  |  |  |  |  |  |  |  | NONE | C
3 | 100nF | ESP32_WROVER_EAGLE-LTSPICE_CC0402 | ESP32_WROVER_EAGLE-LTSPICE_C0402 | C1, C2, C_DELAY | CAPACITOR, European symbol |  |  |  |  |  |  |  |  |  |  |  |  |  |  |  |  |  |  |  |  |  |  |  |  |  |  |  |  |  |  | NONE | C
1 | 100uF TANT | RCL_CPOL-EUCT3528 | RCL_CT3528 | C3 | POLARIZED CAPACITOR, European symbol |  |  |  |  |  |  |  |  |  |  |  |  |  |  |  |  |  |  |  |  |  |  |  | 0 |  |  |  |  |  |  |  | C
16 | 10K | ESP32_WROVER_EAGLE-LTSPICE_RR0402 | ESP32_WROVER_EAGLE-LTSPICE_R0402 | R1, R1_PINH, R1_PINH1, R2-PINH, R2_PINH1, R4, R5, R6, R7, R8, R9, R10, R_BOOT, R_CHANCE, R_CL1, R_RESET | RESISTOR, European symbol |  |  |  |  |  |  |  |  |  |  |  |  |  |  |  |  |  |  |  |  |  |  |  |  |  |  |  |  |  |  | NONE | R
1 | 10uF | EAGLE-LTSPICE_CC0402 | EAGLE-LTSPICE_C0402 | C7 | CAPACITOR, European symbol |  |  |  |  |  |  |  |  |  |  |  |  |  |  |  |  |  |  |  |  |  |  |  |  |  |  |  |  |  |  | NONE | C
1 | 112A-TAAR-R03_ATTEND | 112A-TAAR-R03_ATTEND | 112ATAARR03ATTEND | J4 | Micro SD Card Socket, Push-Push Type, Top Mount, SMT, H=1.83mm, 10u |  |  |  |  |  |  |  | Micro SD Card Socket | Push-Push Type | Top Mount | SMT | H=1.83mm | 10u |  |  | 1.9mm |  | ATTEND | 112A-TAAR-R03 ATTEND
1 | 15 | ESP32_WROVER_EAGLE-LTSPICE_RR0402 | ESP32_WROVER_EAGLE-LTSPICE_R0402 | R_CAPACITOR | RESISTOR, European symbol |  |  |  |  |  |  |  |  |  |  |  |  |  |  |  |  |  |  |  |  |  |  |  |  |  |  |  |  |  |  | NONE | R
9 | 1uF/50V | ESP32_WROVER_EAGLE-LTSPICE_CC0402 | ESP32_WROVER_EAGLE-LTSPICE_C0402 | EPD_C1, EPD_C2, EPD_C6, EPD_C7, EPD_C8, EPD_C9, EPD_C10, EPD_C11, EPD_C12 | CAPACITOR, European symbol |  |  |  |  |  |  |  |  |  |  |  |  |  |  |  |  |  |  |  |  |  |  |  |  |  |  |  |  |  |  | NONE | C
1 | 2.2 | ESP32_WROVER_EAGLE-LTSPICE_RR0402 | ESP32_WROVER_EAGLE-LTSPICE_R0402 | R2 | RESISTOR, European symbol |  |  |  |  |  |  |  |  |  |  |  |  |  |  |  |  |  |  |  |  |  |  |  |  |  |  |  |  |  |  | NONE | R
1 | 200 | ESP32_WROVER_EAGLE-LTSPICE_RR0402 | ESP32_WROVER_EAGLE-LTSPICE_R0402 | R1_BAT | RESISTOR, European symbol |  |  |  |  |  |  |  |  |  |  |  |  |  |  |  |  |  |  |  |  |  |  |  |  |  |  |  |  |  |  | NONE | R
2 | 20V/4.2A/52m?/1.4W | ESP32_WROVER_SPARKFUN-DISCRETESEMI_MOSFET_PCH-DMG2305UX-7 | ESP32_WROVER_SPARKFUN-DISCRETESEMI_SOT23-3 | Q1, Q2 | P-channel MOSFETs |  |  |  |  |  |  |  |  |  |  |  |  |  |  |  |  |  |  |  |  |  |  |  |  |  |  | TRAN-14388 |  |  |  |  |  |  |  |  |  | 20V/4.2A/52m?/1.4W
1 | 2k | ESP32_WROVER_EAGLE-LTSPICE_RR0402 | ESP32_WROVER_EAGLE-LTSPICE_R0402 | R2_BAT | RESISTOR, European symbol |  |  |  |  |  |  |  |  |  |  |  |  |  |  |  |  |  |  |  |  |  |  |  |  |  |  |  |  |  |  | NONE | R
4 | 4.7uF | EAGLE-LTSPICE_CC0402 | EAGLE-LTSPICE_C0402 | C1_BAT, C1_BAT1, C1_BAT2, C5_USB | CAPACITOR, European symbol |  |  |  |  |  |  |  |  |  |  |  |  |  |  |  |  |  |  |  |  |  |  |  |  |  |  |  |  |  |  | NONE | C
1 | 4.7uF | ESP32_WROVER_EAGLE-LTSPICE_CC0402 | ESP32_WROVER_EAGLE-LTSPICE_C0402 | C2_BAT | CAPACITOR, European symbol |  |  |  |  |  |  |  |  |  |  |  |  |  |  |  |  |  |  |  |  |  |  |  |  |  |  |  |  |  |  | NONE | C
1 | 4.7uF/25V | EAGLE-LTSPICE_CC0402 | EAGLE-LTSPICE_C0402 | C4 | CAPACITOR, European symbol |  |  |  |  |  |  |  |  |  |  |  |  |  |  |  |  |  |  |  |  |  |  |  |  |  |  |  |  |  |  | NONE | C
2 | 5k1 | ESP32_WROVER_EAGLE-LTSPICE_RR0402 | ESP32_WROVER_EAGLE-LTSPICE_R0402 | R2_USB, R2_USB1 | RESISTOR, European symbol |  |  |  |  |  |  |  |  |  |  |  |  |  |  |  |  |  |  |  |  |  |  |  |  |  |  |  |  |  |  | NONE | R
1 | 68uH | 744043680IND_4828-WE-TPC_WRE | IND_4828-WE-TPC_WRE | L1 |  |  |  |  |  |  | Copyright (C) 2024 Ultra Librarian. All rights reserved. |  |  |  |  |  |  |  | 744043680 |  | Wurth Electronics
1 | BD5229G-TR | BD5229G-TR | SOT95P280X125-5N | IC1 | Voltage Detector with Adjustable Delay Time: CMOS processes are utilized to develop high precision, low current consumption CMOS reset ICs that allow arbitrary setting of the delay time. The extensive lineup includes both Nch Open Drain and CMOS output types in a wide range of detection voltages (from 2.3V to 6.0V, in 0.1V steps), enabling selection of the ideal solution based on customer requirements. In addition, the entire series is of course both lead-free and RoHS-compliant. |  |  |  |  |  |  |  | Voltage Detector with Adjustable Delay Time: CMOS processes are utilized to develop high precision | low current consumption CMOS reset ICs that allow arbitrary setting of the delay time. The extensive lineup includes both Nch Open Drain and CMOS output types in a wide range of detection voltages (from 2.3V to 6.0V | in 0.1V steps) | enabling selection of the ideal solution based on customer requirements. In addition | the entire series is of course both lead-free and RoHS-compliant. |  |  | 1.25mm |  | ROHM Semiconductor | BD5229G-TR |  |  | 755-BD5229G-TR | https://www.mouser.co.uk/ProductDetail/ROHM-Semiconductor/BD5229G-TR?qs=4kLU8WoGk0vvnhrrYwdszw%3D%3D
1 | BME680 | ESP32_WROVER_BME680_BME680 | ESP32_WROVER_BME680_PSON80P300X300X100-8N | SENSOR2 | Integrated Environmental Unit |  |  | Unavailable |  |  |  |  | Integrated Environmental Unit |  |  |  |  |  |  | Bosch Sensortec |  |  |  |  |  | BME680 |  | LGA-8 Bosch Tools |  |  | None
3 | BUTTON_CUSYOMV1 | BUTTON_CUSYOMV1 | MYBUTTON | BOOT_BUTTON, CHANGE_BUTTON, RESET_BUTTON
1 | CPH3225A | CPH3225A | CAPCP3225X100N | C10_SUPERCAP | Cap 0.011F 3.3V 1210 Flat Check availability |  |  | Not in stock |  | https://www.snapeda.com/parts/CPH3225A/Seiko+Instruments/view-part/?ref=eda |  |  | 11 mF (EDLC) Supercapacitor 3.3 V 1210 (3225 Metric) - - |  |  |  |  |  |  | Seiko Instruments |  |  |  |  |  | CPH3225A |  | 1210 Seiko |  |  | None |  | https://www.snapeda.com/api/url_track_click_mouser/?unipart_id=562593&manufacturer=Seiko Instruments&part_name=CPH3225A&search_term=None |  | https://www.snapeda.com/parts/CPH3225A/Seiko+Instruments/view-part/?ref=snap
1 | DS3231SN# | DS3231SN# | SOIC127P1032X265-16N | U3 | Real Time Clock Serial 16-Pin SOIC W T/R Check availability |  |  | In Stock |  | https://www.snapeda.com/parts/DS3231SN%23/Analog+Devices/view-part/?ref=eda |  |  | Extremely Accurate I2C-Integrated RTC/TCXO/Crystal |  |  |  |  |  |  | Analog Devices |  |  |  |  |  | DS3231SN# |  | SOIC-16 Maxim |  |  | None |  | https://www.snapeda.com/api/url_track_click_mouser/?unipart_id=99048&manufacturer=Analog Devices&part_name=DS3231SN#&search_term=None |  | https://www.snapeda.com/parts/DS3231SN%23/Analog+Devices/view-part/?ref=snap
1 | ESP32-C6-WROOM-1-N8 | ESP32-C6-WROOM-1-N8 | XCVR_ESP32-C6-WROOM-1-N8 | U2 | Check availability |  |  | In Stock |  | https://www.snapeda.com/parts/ESP32-C6-WROOM-1-N8/Espressif+Systems/view-part/?ref=eda |  |  | Multiprotocol Modules ESP32-C6 module | Wi-Fi 6 in 2.4 GHz band | Bluetooth 5 | Zigbee 3.0 and Thread. ESP34-WROOM Compatible - ENGINEERING SAMPLE |  |  |  |  |  |  | Espressif Systems |  |  |  |  |  | ESP32-C6-WROOM-1-N8 |  | None |  |  | None |  |  |  | https://www.snapeda.com/parts/ESP32-C6-WROOM-1-N8/Espressif+Systems/view-part/?ref=snap
1 | ESP32C6_VARISTORCN1812 | ESP32C6_VARISTORCN1812 | ESP32C6_VARISTOR_CT/CN1812 | PFMF.050.1 | VARISTOR |  |  |  |  |  |  |  |  |  |  |  |  |  |  |  |  |  |  |  |  |  |  |  | 0
1 | ESP32_WROVER_AVX---SD0805S020S1R0_AVX_SD0805S020S1R0_0_0AVX_SD0805S020S1R0_0_0 | ESP32_WROVER_AVX---SD0805S020S1R0_AVX_SD0805S020S1R0_0_0AVX_SD0805S020S1R0_0_0 | ESP32_WROVER_AVX---SD0805S020S1R0_AVX_SD0805S020S1R0_0 | D6 | Schottky Barrier Rectifier Diode |  |  |  | No |  |  | http://datasheets.avx.com/schottky.pdf |  | DIODE SCHOTTKY 20V 1A 0805 | 478-7800-1-ND |  | yes |  |  | AVX |  | 581-SD0805S020S1R0 |  |  |  |  |  | 0805 (2012 metric) |  | D |  |  |  | yes |  |  |  |  | +125°C | -55°C
1 | FH34SRJ-24S-0.5SH_99_ | FH34SRJ-24S-0.5SH_99_ | FH34SRJ24S05SH99 | J1 | (0.50mm) Surface Mount, Right Angle |  |  |  |  |  |  |  | 24 Position FFC | FPC Connector Contacts | (0.50mm) Surface Mount | Right Angle |  |  | 1.1mm |  | Hirose | FH34SRJ-24S-0.5SH(99) |  |  | 798-FH34SRJ24S05SH99 | https://www.mouser.co.uk/ProductDetail/Hirose-Connector/FH34SRJ-24S-0.5SH99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
1 | MAX17048G+T10 | MAX17048G+T10 | SON50P200X200X80-9N | U4 | Check availability |  |  | In Stock |  | https://www.snapeda.com/parts/MAX17048G+T10/Analog+Devices/view-part/?ref=eda |  |  | 3µA 1-Cell/2-Cell Fuel Gauge with ModelGauge |  |  |  |  |  |  | Analog Devices |  |  |  |  |  | MAX17048G+T10 |  | TDFN-8 Maxim |  |  | None |  | https://www.snapeda.com/api/url_track_click_mouser/?unipart_id=329239&manufacturer=Analog Devices&part_name=MAX17048G+T10&search_term=None |  | https://www.snapeda.com/parts/MAX17048G+T10/Analog+Devices/view-part/?ref=snap
3 | MBR0530 | MBR0530 | SOD3716X135N | D3, D4, D5 | ON SEMICONDUCTOR - MBR0530 - DIODE, SCHOTTKY, 0.5A, 30V, SOD-123 |  |  | In Stock |  | https://www.snapeda.com/parts/MBR0530/Onsemi/view-part/?ref=eda |  |  | Diode Schottky 30 V 500mA Surface Mount SOD-123 |  |  |  |  |  |  | ON Semiconductor |  |  |  |  |  | MBR0530 |  | SOD-123-2 ON Semiconductor |  |  | None |  | https://www.snapeda.com/api/url_track_click_mouser/?unipart_id=179458&manufacturer=ON Semiconductor&part_name=MBR0530&search_term=None |  | https://www.snapeda.com/parts/MBR0530/Onsemi/view-part/?ref=snap
1 | MCP73831 | ESP32_WROVER_SPARKFUN-IC-POWER_MCP73831 | ESP32_WROVER_SPARKFUN-IC-POWER_SOT23-5 | U1 | MCP73831T Li-Ion, Li-Pol Controller |  |  |  |  |  |  |  |  |  |  |  |  |  |  |  |  |  |  |  |  |  |  |  |  |  |  | IC-09995
6 | PGB1010603MR | PGB1010603MR | DIOC1608X36N | D7, D8, D9, D10, D11, D12 | Check availability |  |  | In Stock |  | https://www.snapeda.com/parts/PGB1010603MR/Littelfuse/view-part/?ref=eda |  |  | 150V (Typ) Clamp - Ipp Tvs Diode Surface Mount 0603 (1608 Metric) |  |  |  |  |  |  | Littelfuse Inc. |  |  |  |  |  | PGB1010603MR |  | 0603 Littelfuse Inc. |  |  | None |  | https://www.snapeda.com/api/url_track_click_mouser/?unipart_id=5659453&manufacturer=Littelfuse Inc.&part_name=PGB1010603MR&search_term=None |  | https://www.snapeda.com/parts/PGB1010603MR/Littelfuse/view-part/?ref=snap
1 | QWIIC_RIGHT_ANGLE | QWIIC_CONNECTORJS-1MM | JST04_1MM_RA | J3 | SparkFun I2C Standard Qwiic Connector |  |  |  |  |  |  |  |  |  |  |  |  |  |  |  |  |  |  |  |  |  |  |  |  |  |  | CONN-13694 |  |  |  |  |  |  |  |  |  | QWIIC_RIGHT_ANGLE
1 | SAMACSYS_PARTS_USB4110-GF-A | SAMACSYS_PARTS_USB4110-GF-A | SAMACSYS_PARTS_USB4110GFA | J2 | CONN USB 2.0 TYPE-C R/A SMT |  |  |  |  |  |  |  | CONN USB 2.0 TYPE-C R/A SMT |  |  | 3.26mm |  | GCT (GLOBAL CONNECTOR TECHNOLOGY) | USB4110-GF-A |  |  | 640-USB4110-GF-A | https://www.mouser.co.uk/ProductDetail/GCT/USB4110-GF-A?qs=KUoIvG%2F9IlYiZvIXQjyJeA%3D%3D
1 | SD0805S020S1R0 | ESP32_WROVER_AVX---SD0805S020S1R0_AVX_SD0805S020S1R0_0_0AVX_SD0805S020S1R0_0_0 | ESP32_WROVER_AVX---SD0805S020S1R0_AVX_SD0805S020S1R0_0 | D2 | Schottky Barrier Rectifier Diode |  |  |  | No |  |  | http://datasheets.avx.com/schottky.pdf |  | DIODE SCHOTTKY 20V 1A 0805 | 478-7800-1-ND |  | yes |  |  | AVX |  | 581-SD0805S020S1R0 |  |  |  |  |  | 0805 (2012 metric) |  | D |  |  |  | yes |  |  |  |  | +125°C | -55°C
1 | SI1308EDL-T1-GE3 | SI1308EDL-T1-GE3 | SOT65P210X110-3N | Q3 | MOSFET N-Ch 30V 1.5A TrenchFET SC70 Vishay Si1308EDL-T1-GE3 N-channel MOSFET Transistor, 1.5 A, 30 V, 3-Pin SC-70 |  |  | In Stock |  | https://www.snapeda.com/parts/SI1308EDL-T1-GE3/Vishay+Siliconix/view-part/?ref=eda |  |  | Si1308EDL-T1-GE3 N-channel MOSFET Transistor | 1.5 A | 30 V | 3-Pin SC-70 | Siliconix / Vishay SI1308EDL-T1-GE3 |  |  |  |  |  |  | Vishay Siliconix |  |  |  |  |  | SI1308EDL-T1-GE3 |  | SOT-323 Vishay Semiconductor |  |  | None |  | https://www.snapeda.com/api/url_track_click_mouser/?unipart_id=274603&manufacturer=Vishay Siliconix&part_name=SI1308EDL-T1-GE3&search_term=None |  | https://www.snapeda.com/parts/SI1308EDL-T1-GE3/Vishay+Siliconix/view-part/?ref=snap
17 | TPTP20R | TPTP20R | TP20R | TP1, TP2, TP3, TP4, TP5, TP6, TP7, TP8, TP9, TP10, TP11, TP12, TP13, TP14, TP15, TP16, TP17 | Test pad |  |  |  |  |  |  |  |  |  |  |  |  |  |  |  |  |  |  |  |  |  |  |  | 2
1 | USBLC6-2SC6Y | USBLC6-2SC6Y | SOT95P280X145-6N | D1 | Low Cap. ESD Protection Auto SOT-23-6 STMicroelectronics USBLC6-2SC6Y, Dual Uni-Directional TVS Diode Array, 6-Pin SOT-23 |  |  | In Stock |  | https://www.snapeda.com/parts/USBLC6-2SC6Y/STMicroelectronics/view-part/?ref=eda |  |  | 17V Clamp 5A (8/20µs) Ipp Tvs Diode Surface Mount SOT-23-6 |  |  |  |  |  |  | STMicroelectronics |  |  |  |  |  | USBLC6-2SC6Y |  | SOT-23-6 STMicroelectronics |  |  | None |  |  |  | https://www.snapeda.com/parts/USBLC6-2SC6Y/STMicroelectronics/view-part/?ref=snap
1 | W25Q512JVEIQ | W25Q512JVEIQ | SON127P600X800X80-9N | U5 | Check availability |  |  | In Stock |  | https://www.snapeda.com/parts/W25Q512JVEIQ/Winbond+Electronics/view-part/?ref=eda |  |  | FLASH - NOR Memory IC 512Mb (64M x 8) SPI - Quad I/O 133 MHz 8-WSON (8x6) |  |  |  |  |  |  | Winbond Electronics |  |  |  |  |  | W25Q512JVEIQ |  | Package |  |  | None |  |  |  | https://www.snapeda.com/parts/W25Q512JVEIQ/Winbond+Electronics/view-part/?ref=snap
1 | XC6220A331MR-G | XC6220A331MR-G | SOT95P280X120-5N | IC4 | LDO Voltage Regulators |  |  |  |  |  |  |  | LDO Voltage Regulators |  |  | 1.2mm |  | Torex | XC6220A331MR-G |  |  | 865-XC6220A331MR-G | https://www.mouser.co.uk/ProductDetail/Torex-Semiconductor/XC6220A331MR-G?qs=AsjdqWjXhJ8ZSWznL1J0gg%3D%3D

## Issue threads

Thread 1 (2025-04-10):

Erori la Design Rules Check

gabrielpitic, 2025-04-10:
### Descriere

DRC-ul a generat 4 erori.

### Erori

- Via-SMD overlap la componenta L1
- 2x SMD pad - copper width la componenta U4
- SMD pad - copper width la componenta L1

Closed 2025-04-12.

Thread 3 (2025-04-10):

Componente amplasate incorect

gabrielpitic, 2025-04-10:
### Descriere

Anumite componente sunt amplasate incorect pe PCB, ducand la nesuprapunerea lor cu pad-urile oferite de placa.

### Probleme

Cele 2 componente care sunt pozitionate neadecvat sunt:

- IC1
- IC4

Closed 2025-04-12.

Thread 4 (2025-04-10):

Mutare image.png in directorul Images/

gabrielpitic, 2025-04-10:
### Descriere

Mutarea imaginii corespunzatoare diagramei bloc din `root` in directorul `Images/` pentru a pastra o structura cat mai curata a proiectului.

### Probleme

Referinta din `README.md` trebuie modificata:

#### Original:
`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`

#### Nou:
`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`

Closed 2025-04-12.

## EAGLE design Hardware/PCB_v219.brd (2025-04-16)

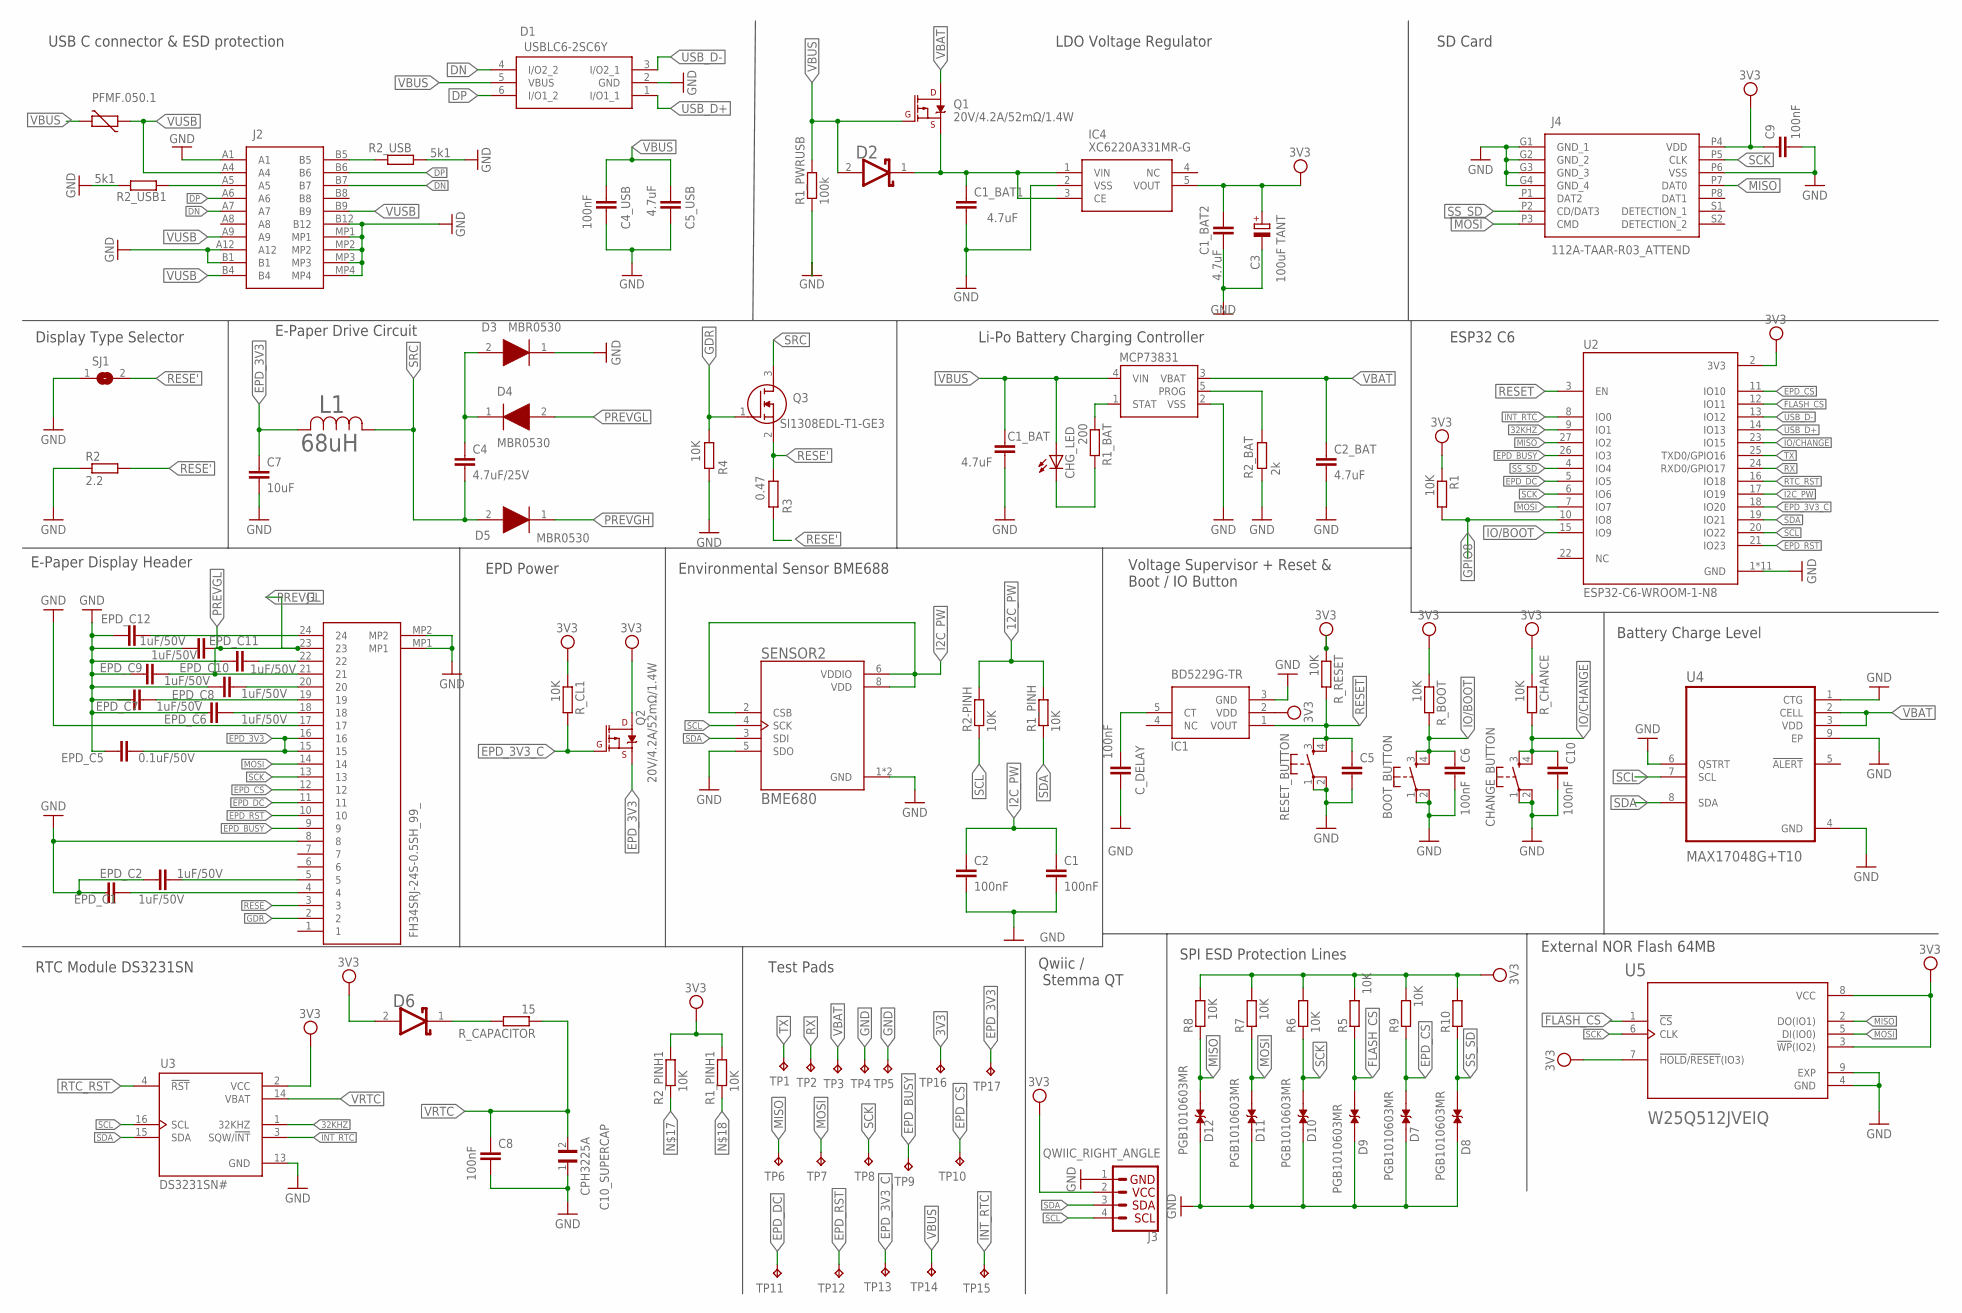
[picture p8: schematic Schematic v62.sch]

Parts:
BOOT_BUTTON: BUTTON_CUSYOMV1; MYBUTTON
C1, C2: 100nF; ESP32_WROVER_EAGLE-LTSPICE_C0402
C1_BAT, C1_BAT1, C1_BAT2, C5_USB: 4.7uF; EAGLE-LTSPICE_C0402
C2_BAT: 4.7uF; ESP32_WROVER_EAGLE-LTSPICE_C0402
C3: 100uF TANT; RCL_CT3528
C4: 4.7uF/25V; EAGLE-LTSPICE_C0402
C4_USB, C6, C8, C9, C10: 100nF; EAGLE-LTSPICE_C0402
C5: ESP32_WROVER_EAGLE-LTSPICE_CC0402; ESP32_WROVER_EAGLE-LTSPICE_C0402
C7: 10uF; EAGLE-LTSPICE_C0402
C10_SUPERCAP: CPH3225A; CAPCP3225X100N
CHANGE_BUTTON: BUTTON_CUSYOMV1; MYBUTTON
CHG_LED: ADAFRUIT_LEDCHIP-LED0603; ADAFRUIT_CHIP-LED0603
C_DELAY: 100nF; ESP32_WROVER_EAGLE-LTSPICE_C0402
D1: USBLC6-2SC6Y; SOT95P280X145-6N
D2: SD0805S020S1R0; ESP32_WROVER_AVX---SD0805S020S1R0_AVX_SD0805S020S1R0_0
D3, D4, D5: MBR0530; SOD3716X135N
D6: ESP32_WROVER_AVX---SD0805S020S1R0_AVX_SD0805S020S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; ESP32_WROVER_AVX---SD0805S020S1R0_AVX_SD0805S020S1R0_0
D7, D8, D9, D10, D11, D12: PGB1010603MR; DIOC1608X36N
EPD_C1, EPD_C2, EPD_C6, EPD_C7, EPD_C8, EPD_C9, EPD_C10, EPD_C11, EPD_C12: 1uF/50V; ESP32_WROVER_EAGLE-LTSPICE_C0402
EPD_C5: 0.1uF/50V; ESP32_WROVER_EAGLE-LTSPICE_C0402
IC1: BD5229G-TR; SOT95P280X125-5N
IC4: XC6220A331MR-G; SOT95P280X120-5N
J1: FH34SRJ-24S-0.5SH_99_; FH34SRJ24S05SH99
J2: SAMACSYS_PARTS_USB4110-GF-A; SAMACSYS_PARTS_USB4110GFA
J3: QWIIC_RIGHT_ANGLE; JST04_1MM_RA
J4: 112A-TAAR-R03_ATTEND; 112ATAARR03ATTEND
L1: 68uH; IND_4828-WE-TPC_WRE
PFMF.050.1: ESP32C6_VARISTORCN1812; ESP32C6_VARISTOR_CT/CN1812
Q1, Q2: 20V/4.2A/52mΩ/1.4W; ESP32_WROVER_SPARKFUN-DISCRETESEMI_SOT23-3
Q3: SI1308EDL-T1-GE3; SOT65P210X110-3N
R1, R1_PINH, R1_PINH1, R2-PINH, R2_PINH1, R4, R5, R6, R7, R8, R9, R10: 10K; ESP32_WROVER_EAGLE-LTSPICE_R0402
R1_BAT: 200; ESP32_WROVER_EAGLE-LTSPICE_R0402
R1_PWRUSB: 100k; ESP32_WROVER_EAGLE-LTSPICE_R0402
R2: 2.2; ESP32_WROVER_EAGLE-LTSPICE_R0402
R2_BAT: 2k; ESP32_WROVER_EAGLE-LTSPICE_R0402
R2_USB, R2_USB1: 5k1; ESP32_WROVER_EAGLE-LTSPICE_R0402
R3: 0.47; ESP32_WROVER_EAGLE-LTSPICE_R0402
RESET_BUTTON: BUTTON_CUSYOMV1; MYBUTTON
R_BOOT: 10K; ESP32_WROVER_EAGLE-LTSPICE_R0402
R_CAPACITOR: 15; ESP32_WROVER_EAGLE-LTSPICE_R0402
R_CHANCE: 10K; ESP32_WROVER_EAGLE-LTSPICE_R0402
R_CL1: 10K; ESP32_WROVER_EAGLE-LTSPICE_R0402
R_RESET: 10K; ESP32_WROVER_EAGLE-LTSPICE_R0402
SENSOR2: BME680; ESP32_WROVER_BME680_PSON80P300X300X100-8N
SJ1: SJ
TP1, TP2, TP3, TP4, TP5, TP6, TP7, TP8, TP9, TP10, TP11, TP12, TP13, TP14, TP15, TP16, TP17: TPTP20R; TP20R
U1: MCP73831; ESP32_WROVER_SPARKFUN-IC-POWER_SOT23-5
U2: ESP32-C6-WROOM-1-N8; XCVR_ESP32-C6-WROOM-1-N8
U3: DS3231SN#; SOIC127P1032X265-16N
U4: MAX17048G+T10; SON50P200X200X80-9N
U5: W25Q512JVEIQ; SON127P600X800X80-9N

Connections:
3V3: C1_BAT2.1, C3.+, C9.1, D6.2 (ANODE), IC1.2 (VDD), IC4.5 (VOUT), J3.2, J4.P4 (VDD), Q2.3 (D), R1.1, R1_PINH1.2, R2_PINH1.2, R5.2, R6.2, R7.2, R8.2, R9.2, R10.2, R_BOOT.1, R_CHANCE.2, R_CL1.1, R_RESET.1, TP16.TP, U2.2 (3V3), U3.2 (VCC), U5.3 (!WP!(IO2)), U5.7 (!HOLD!/!RESET!(IO3)), U5.8 (VCC)
12C_PW: R1_PINH.2, R2-PINH.2
32KHZ: U2.9 (IO1), U3.1 (32KHZ)
DN: D1.4 (I/O2_2), J2.A7, J2.B7
DP: D1.6 (I/O1_2), J2.A6, J2.B6
EPD_3V3: C7.1, EPD_C5.1, J1.15, J1.16, L1.2, Q2.2 (S), TP17.TP
EPD_3V3_C: Q2.1 (G), R_CL1.2, TP13.TP, U2.18 (IO20)
EPD_BUSY: J1.9, TP9.TP, U2.26 (IO3)
EPD_CS: D7.2, J1.12, R9.1, TP10.TP, U2.11 (IO10)
EPD_DC: J1.11, TP11.TP, U2.5 (IO5)
EPD_RST: J1.10, TP12.TP, U2.21 (IO23)
FLASH_CS: D9.2, R5.1, U2.12 (IO11), U5.1 (!CS)
GDR: J1.2, Q3.1 (G), R4.2
GND: BOOT_BUTTON.1, BOOT_BUTTON.2, C1.2, C1_BAT.2, C1_BAT1.2, C1_BAT2.2, C2.2, C2_BAT.2, C3.-, C4_USB.2, C5.2, C5_USB.2, C6.2, C7.2, C8.2, C9.2, C10.2, C10_SUPERCAP.1, CHANGE_BUTTON.1, CHANGE_BUTTON.2, C_DELAY.2, D1.2 (GND), D3.1 (K), D7.1, D8.1, D9.1, D10.1, D11.1, D12.1, EPD_C1.2, EPD_C2.2, EPD_C5.2, EPD_C6.2, EPD_C7.2, EPD_C8.2, EPD_C9.2, EPD_C10.2, EPD_C11.2, EPD_C12.2, IC1.3 (GND), IC4.2 (VSS), J1.8, J1.17, J1.MP1, J1.MP2, J2.A1, J2.A12, J2.B1, J2.B12, J2.MP1, J2.MP2, J2.MP3, J2.MP4, J3.1, J4.G1 (GND_1), J4.G2 (GND_2), J4.G3 (GND_3), J4.G4 (GND_4), J4.P6 (VSS), R1_PWRUSB.1, R2.1, R2_BAT.2, R2_USB.2, R2_USB1.1, R4.1, RESET_BUTTON.1, RESET_BUTTON.2, SENSOR2.1 (GND), SENSOR2.5 (SDO), SENSOR2.7 (GND), SJ1.1, TP4.TP, TP5.TP, U1.2 (VSS), U2.1 (GND), U2.28 (GND), U2.29_1 (GND), U2.29_2 (GND), U2.29_3 (GND), U2.29_4 (GND), U2.29_5 (GND), U2.29_6 (GND), U2.29_7 (GND), U2.29_8 (GND), U2.29_9 (GND), U3.13 (GND), U4.1 (CTG), U4.4 (GND), U4.6 (QSTRT), U4.9 (EP), U5.4 (GND), U5.9 (EXP)
GPIO8: R1.2, U2.10 (IO8)
I2C_PW: C1.1, C2.1, SENSOR2.2 (CSB), SENSOR2.6 (VDDIO), SENSOR2.8 (VDD), U2.17 (IO19)
INT_RTC: TP15.TP, U2.8 (IO0), U3.3 (SQW/!INT)
IO/BOOT: BOOT_BUTTON.3, BOOT_BUTTON.4, C6.1, R_BOOT.2, U2.15 (IO9)
IO/CHANGE: C10.1, CHANGE_BUTTON.3, CHANGE_BUTTON.4, R_CHANCE.1, U2.23 (IO15)
MISO: D12.2, J4.P7 (DAT0), R8.1, TP6.TP, U2.27 (IO2), U5.2 (DO(IO1))
MOSI: D11.2, J1.14, J4.P3 (CMD), R7.1, TP7.TP, U2.7 (IO7), U5.5 (DI(IO0))
unnamed: J2.B5, R2_USB.1
unnamed: J2.A5, R2_USB1.2
unnamed: C1_BAT1.1, D2.1 (CATHODE), IC4.1 (VIN), IC4.3 (CE), Q1.2 (S)
unnamed: C4.1, D3.2 (A), D4.1 (K)
unnamed: R1_BAT.1, U1.1 (STAT)
unnamed: CHG_LED.C, R1_BAT.2
unnamed: EPD_C12.1, J1.24
unnamed: R2_BAT.1, U1.5 (PROG)
unnamed: D6.1 (CATHODE), R_CAPACITOR.2
unnamed: EPD_C10.1, J1.22
unnamed: C_DELAY.1, IC1.5 (CT)
unnamed: EPD_C8.1, J1.20
unnamed: EPD_C7.1, J1.19
unnamed: EPD_C6.1, J1.18
unnamed: EPD_C1.1, J1.4
unnamed: EPD_C2.1, J1.5
PREVGH: D5.1 (K)
PREVGL: D4.2 (A), EPD_C9.1, EPD_C11.1, J1.21, J1.23
RESE: J1.3
RESE': Q3.2 (S), R2.2, R3.1, R3.2, SJ1.2
RESET: C5.1, IC1.1 (VOUT), RESET_BUTTON.3, RESET_BUTTON.4, R_RESET.2, U2.3 (EN)
RTC_RST: U2.16 (IO18), U3.4 (!RST)
RX: TP2.TP, U2.24 (RXD0/GPIO17)
SCK: D10.2, J1.13, J4.P5 (CLK), R6.1, TP8.TP, U2.6 (IO6), U5.6 (CLK)
SCL: J3.4, R2-PINH.1, SENSOR2.4 (SCK), U2.20 (IO22), U3.16 (SCL), U4.7 (SCL)
SDA: J3.3, R1_PINH.1, SENSOR2.3 (SDI), U2.19 (IO21), U3.15 (SDA), U4.8 (SDA)
SRC: C4.2, D5.2 (A), L1.1, Q3.3 (D)
SS_SD: D8.2, J4.P2 (CD/DAT3), R10.1, U2.4 (IO4)
TX: TP1.TP, U2.25 (TXD0/GPIO16)
USB_D+: D1.1 (I/O1_1), U2.14 (IO13)
USB_D-: D1.3 (I/O2_1), U2.13 (IO12)
VBAT: C2_BAT.1, Q1.3 (D), TP3.TP, U1.3 (VBAT), U4.2 (CELL), U4.3 (VDD)
VBUS: C1_BAT.1, C4_USB.1, C5_USB.1, CHG_LED.A, D1.5 (VBUS), D2.2 (ANODE), PFMF.050.1.2, Q1.1 (G), R1_PWRUSB.2, TP14.TP, U1.4 (VIN)
VRTC: C8.1, C10_SUPERCAP.2, R_CAPACITOR.1, U3.14 (VBAT)
VUSB: J2.A4, J2.A9, J2.B4, J2.B9, PFMF.050.1.1

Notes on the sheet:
USB C connector & ESD protection
LDO Voltage Regulator
SD Card
Display Type Selector
E-Paper Drive Circuit
Li-Po Battery Charging Controller
ESP32 C6
E-Paper Display Header
EPD Power
Environmental Sensor BME688
Voltage Supervisor + Reset & Boot / IO Button
Battery Charge Level
RTC Module DS3231SN
Test Pads
Qwiic / Stemma QT
SPI ESD Protection Lines
External NOR Flash 64MB

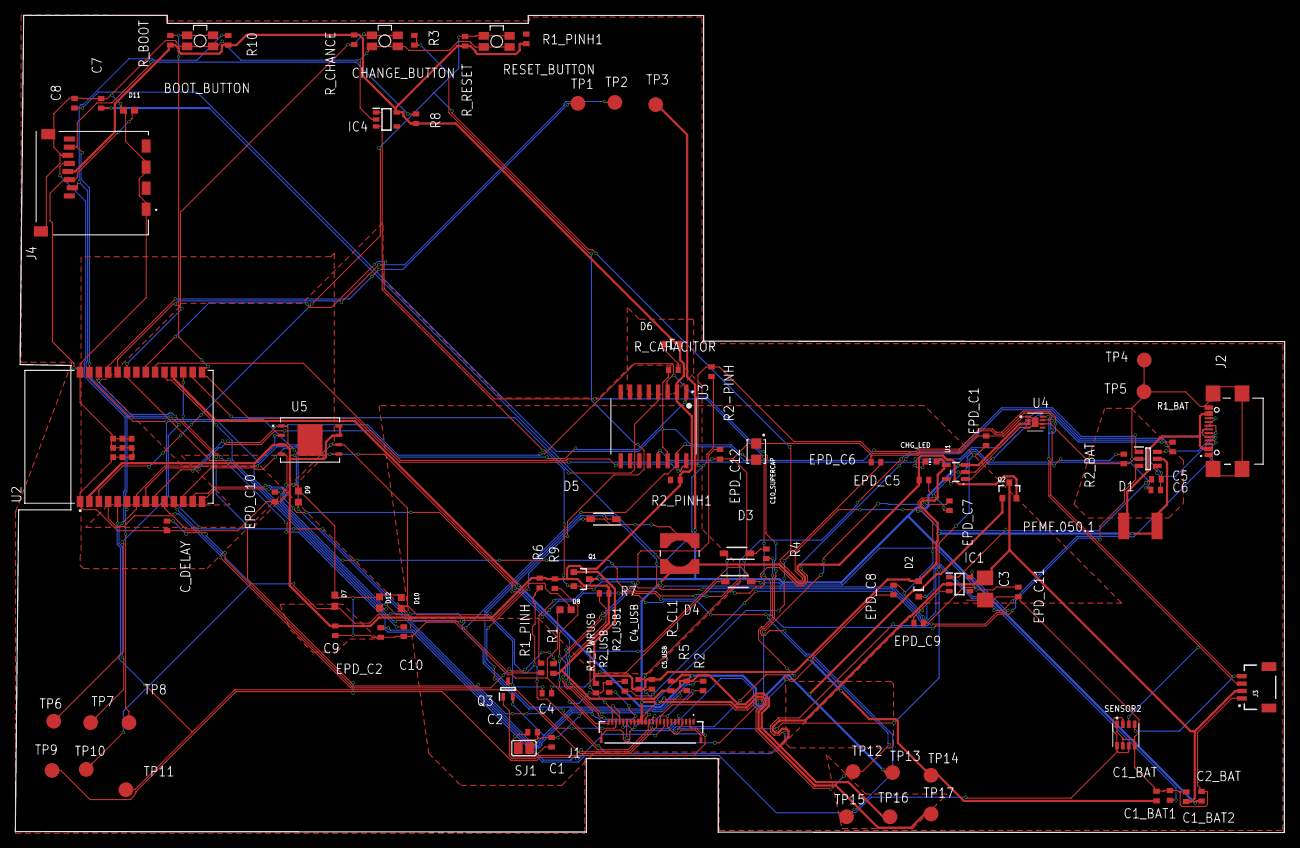
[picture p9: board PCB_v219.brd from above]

Board: 2 copper layers, 171.8 x 110.6 mm, 103 parts (0 on the bottom side), 54 nets.

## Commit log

2025-04-01 Add files via upload
    pcb(cu plan de masa) + schematic
2025-04-01 Add files via upload
    baterie+ecran
    [baterie.f3d, ecran.f3d]
2025-04-01 Add files via upload
    Am scapat de niste erori
2025-04-01 Add files via upload
    Am adaugat elementele 3d pe placa
    [Schematic.sch]
2025-04-02 Add files via upload
    Acum este finalul cu componente 3d incarcate
    [Schematic.sch]
2025-04-02 Add files via upload
    componentele 3d pentru placa
    [04026D105KAT2A.stp, 04026D475MAT2A.stp, 06033D475KAT4A.stp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]
2025-04-05 Proiect final .step si f3z
    [baterie.f3d]
2025-04-12 Add files via upload
    schematic final
    [Schematic.sch]

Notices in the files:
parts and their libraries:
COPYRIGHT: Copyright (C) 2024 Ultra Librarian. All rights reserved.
